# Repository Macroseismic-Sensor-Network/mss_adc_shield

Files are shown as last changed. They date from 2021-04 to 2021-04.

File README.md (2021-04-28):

# MSS ADC Shield

This repository contains the [KiCad](https://www.kicad.org/) design files of the MSS ADC Shield for the [Raspberry Pi](https://www.raspberrypi.org). A PDF of the schematic can be found in the *pdf* folder and the PCB layout files are available in Gerber format in the *gerber* folder.

# License
Copyright 2021, Mertl Research GmbH.
Built upon a design by Daniel Frank.
Licensed under the [CERN-OHL-S v2](https://ohwr.org/cern_ohl_s_v2.txt).

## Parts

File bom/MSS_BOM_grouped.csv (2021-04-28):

Source: | /home/stefan/01_gtd/04_aktuelleProjekte/2019-13_mss_outreach_netidee/02_meilensteine/20200909_mss_produktion/03_adc_platine/MSS.sch
Date: | Mo 28 Sep 2020 15:02:26 CEST
Tool: | Eeschema 5.1.6-c6e7f7d~87~ubuntu18.04.1
Number of components: | 49
ref | value | quantity | manufacturer | manufacturer part number | package | description | footprint | library | part name
C1,C10,C11,C20,C21,C30,C31 | 1uF | 7 | Samsung Electro-Mechanics | CL21B105KBFNNNF | 0805 | Samsung, CL, SMD MLCC, Vielschicht Keramikkondensator X7R, 1μF ±10% / 50V dc, Gehäuse 0805 (2012M) | Capacitor_SMD:C_0805_2012Metric | symbols | C_Small
CON1 | IPL1-104-01-L-S-RE1 | 1 | Samtec | IPL1-104-01-L-S-RE1 | IPL1-104-01-L-S-RE1 | Samtec IPL1 single row, 4 pins, right angle, raised | footprints:IPL1-104-01-L-S-RE1 | symbols | IPL1-104-01-L-S-RE1
CON2,CON3,CON4 | IPL1-102-01-L-S | 3 | Samtec | IPL1-102-01-L-S-RE1 | IPL1-102-01-L-S-RE1 | Samtec IPL1 single row, 2 pins, straight | footprints:IPL1-102-01-L-S | symbols | IPL1-102-01-L-S
D2 | BZT52C2V0S-7-F | 1 | Diodes Incorporated | BZT52C2V0S-7-F | SOD-323 | Zener Diode, 2.0V, 200mW, 5% | Diode_SMD:D_SOD-323 | Device | D_Zener_Small_ALT
D3 | 150080VS75000 | 1 | Würth Elektronik | 150080VS75000 | 0805 | WL-SMCW SMT Mono-color Chip LED Waterclear, green | LED_SMD:LED_0805_2012Metric | Device | LED
D4,D5,D6,D7 | 150080RV54050 | 4 | Würth Elektronik | 150080RV54050 | WL-SBCD-0805 | WL-SBCD SMT Bi-color Chip LED Diffused, red - green | footprints:WL-SBCD-0805 | symbols | 150080RV54050
J1 | RPi | 1 | Samtec | ESQ-120-44-L-D | 20x2 2.54mm pitch | Elevated Socket Strip, 2.54mm Pitch | footprints:RPi_Socket_Strip_Straight_2x20_Pitch2.54mm | Connector_Generic | Conn_02x20_Odd_Even
Q1 | FDS6576 | 1 | ON Semiconductor | FDS6576 | SO-8 | P-Channel MOSFET, 20V DS, 11A, +/-12V GS, 14 mOhm | footprints:ON_751EB_SOIC-8 | symbols | FDS6576
R1,R10,R20,R30 | 1k8 | 4 | TE Connectivity | CRG0805F1K8 | 0805 | TE Connectivity CRG SMD Dickschichtwiderstand, 1,8kΩ ±1% 0,125W, 0805 | Resistor_SMD:R_0805_2012Metric | symbols | R_Small
R2,R4,R5,R6,R7,R8,R9,R15 | 680 | 8 | TE Connectivity | CRG0805F680R | 0805 | TE Connectivity CRG SMD Dickschichtwiderstand, 680Ω ±1% 0,125W, 0805 | Resistor_SMD:R_0805_2012Metric | symbols | R_Small
R11,R12,R21,R22,R31,R32 | 100k | 6 | TE Connectivity | CRG0805F100K | 0805 | TE Connectivity CRG SMD Dickschichtwiderstand, 100kΩ ±1% 0,125W, 0805 | Resistor_SMD:R_0805_2012Metric | symbols | R_Small
R13,R14,R23,R24,R33,R34 | 6k2 | 6 | TE Connectivity | CRCW08056K20FKEA | 0805 | TE Connectivity CRG SMD Dickschichtwiderstand, 6,2kΩ ±1% 0,125W, 0805 | Resistor_SMD:R_0805_2012Metric | symbols | R_Small
R16 | 1k5 | 1 | TE Connectivity | CRG0805F1K5 | 0805 | TE Connectivity CRG SMD Dickschichtwiderstand, 1,5kΩ ±1% 0,125W, 0805 | Resistor_SMD:R_0805_2012Metric | symbols | R_Small
SW1 | 430152043836 | 1 | Würth Elektronik | 430152043836 | 6mm x 6mm | WS-TASV SMT Tact Switch 6x6 mm | footprints:Push_Button_6x6 | Switch | SW_Push
U1,U2,U3 | ADS1114 | 3 | Texas Instruments | ADS1114IDGST | TSSOP10 | ADS111x Ultra-Small, Low-Power, I 2 C-Compatible, 860-SPS, 16-Bit ADCsWith Internal Reference, Oscillator, and Programmable Comparator | Package_SO:TSSOP-10_3x3mm_P0.5mm | symbols | ADS1114
VR1 | 1812L110/33MR | 1 | Littlefuse | 1812L110/33MR | PF1812L | Littelfuse 1.1A Surface Mount Resettable Fuse, 33 V dc | footprints:PF1812L | symbols | Varistance

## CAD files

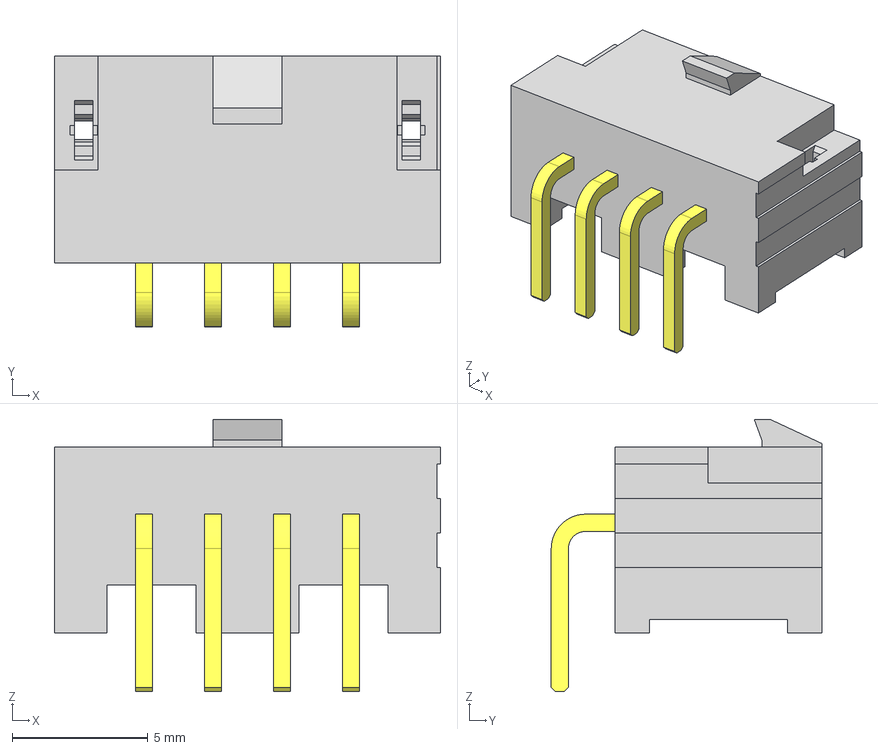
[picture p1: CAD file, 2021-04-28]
3d_models/samtec/IPL1-104-01-L-S-RE1-K.stp
14.2 x 9.97 x 10.0 mm
_IPL1-104-01-S-RE1-K_HDR
_T-1S64-01-04-S-RE1

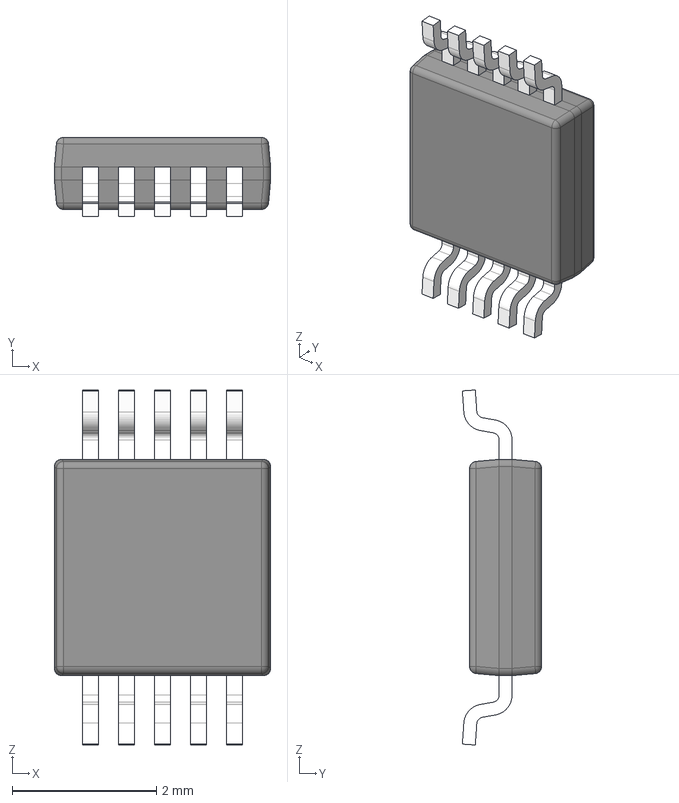
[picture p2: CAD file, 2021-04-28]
3d_models/texas_instruments/ADS1114_DGS0010A.stp
3.00 x 1.10 x 4.93 mm
BODY-SO
LEAD-SO x 10
PIN1-ID

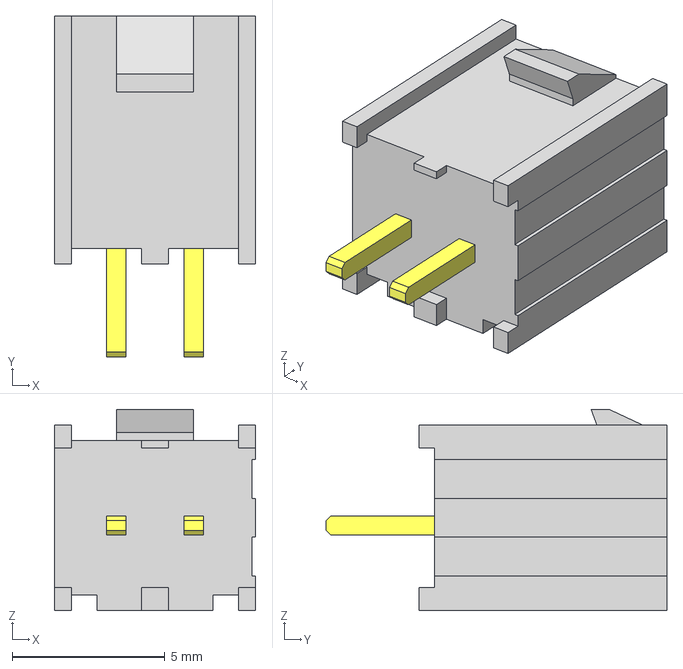
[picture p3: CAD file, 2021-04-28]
3d_models/samtec/IPL1-102-01-L-S-K.stp
6.60 x 11.2 x 6.60 mm
_IPL1-102-01-S-K_HDR
_T-1S64-01-02-S

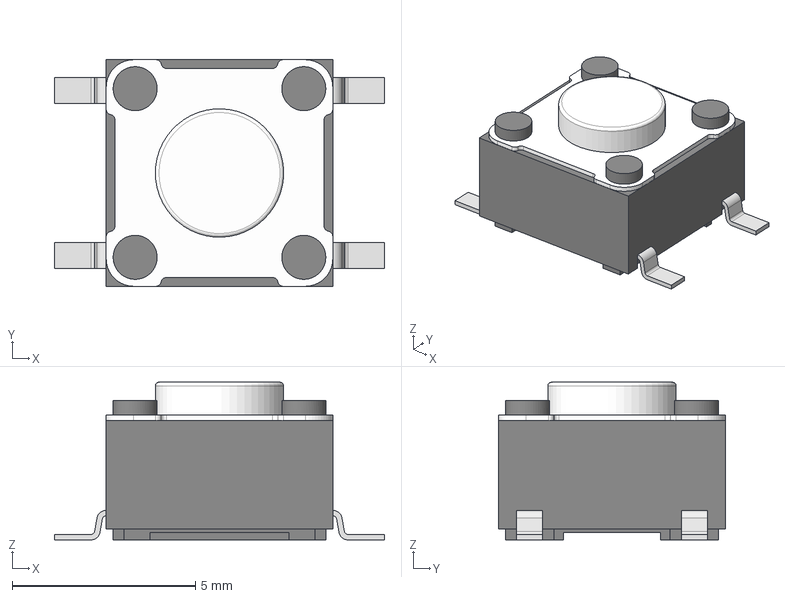
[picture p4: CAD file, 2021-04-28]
3d_models/wuerth_elektronik/430152043836_Download_STP_430152043836_rev1.stp
9.00 x 6.20 x 4.30 mm

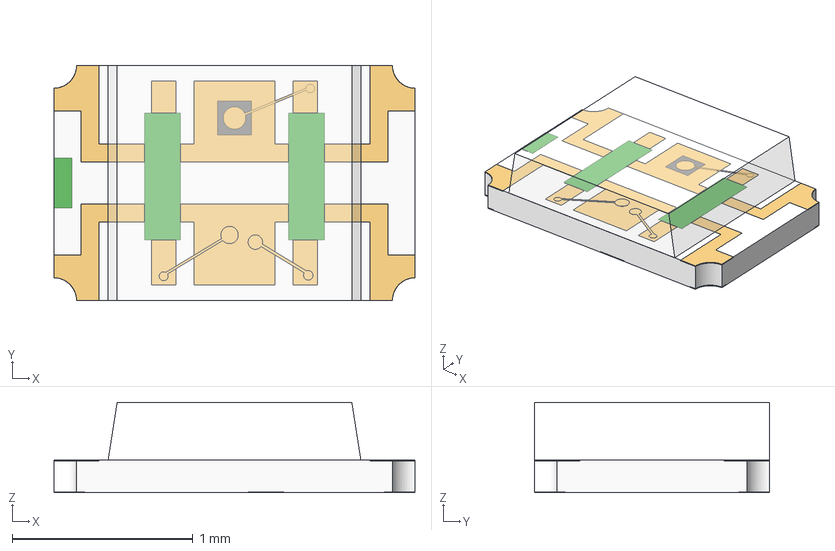
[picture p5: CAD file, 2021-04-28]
3d_models/wuerth_elektronik/150080RV54050_Download_STEP_150080xx54050_rev1.stp
2.00 x 1.30 x 0.501 mm
Pins
Dome

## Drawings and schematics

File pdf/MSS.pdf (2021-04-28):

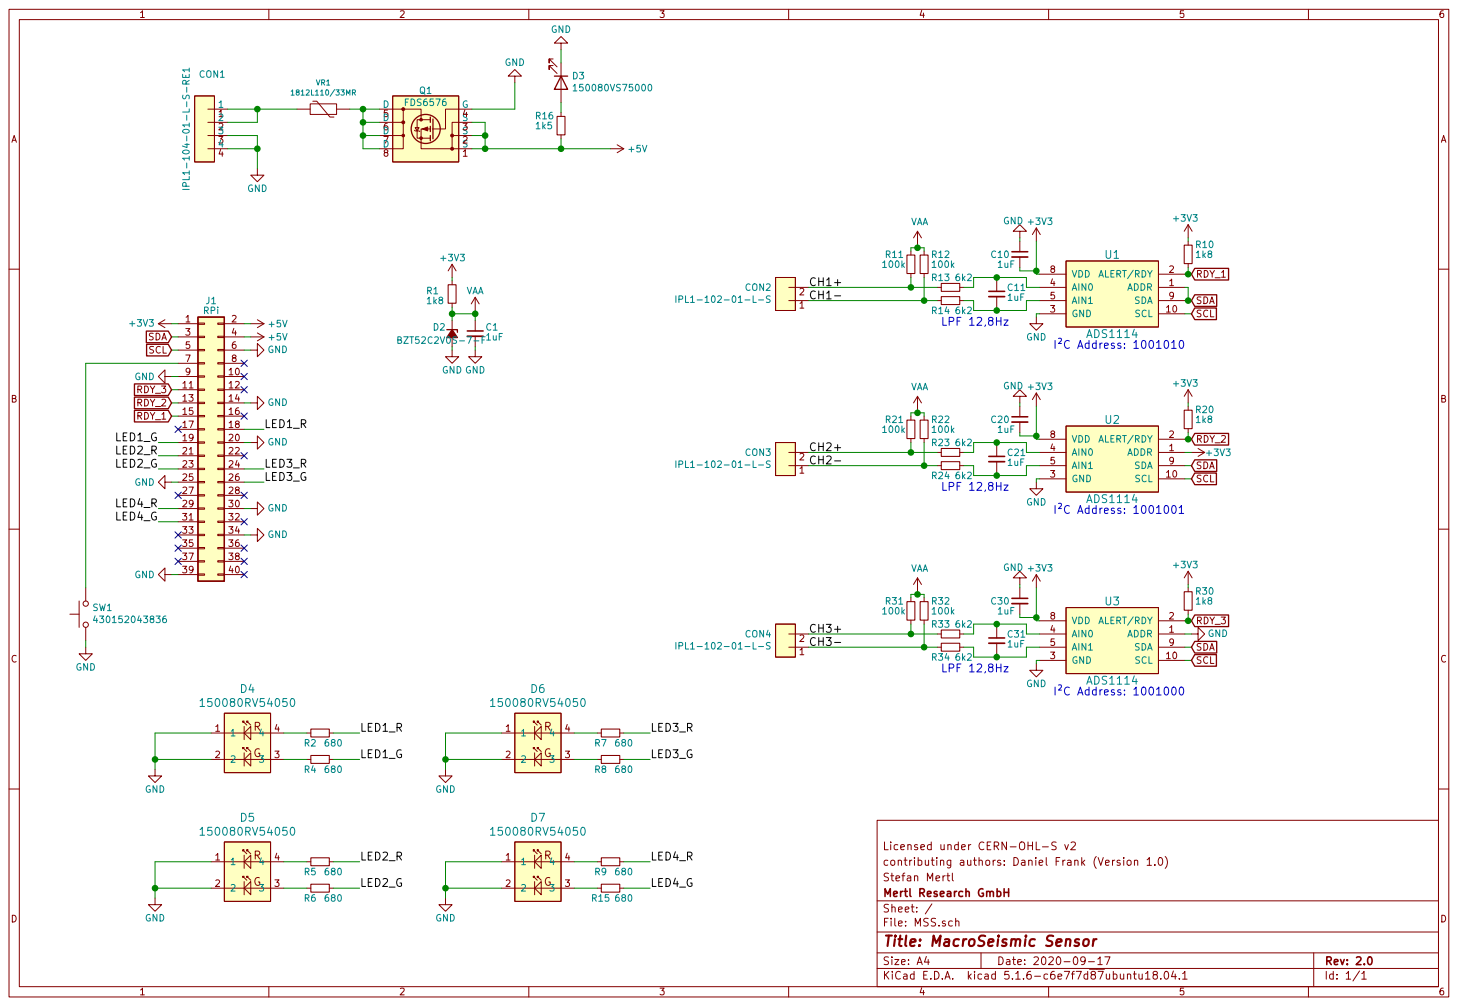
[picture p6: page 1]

RDY_1 SDA RDY_2 SCL SCL RDY_3 SDA

Stefan Mertl contributing authors: Daniel Frank (Version 1.0) Licensed under CERN-OHL-S v2 R15 680

Id: 1/1 Title: MacroSeismic Sensor File: MSS.sch Sheet: / Mertl Research GmbH

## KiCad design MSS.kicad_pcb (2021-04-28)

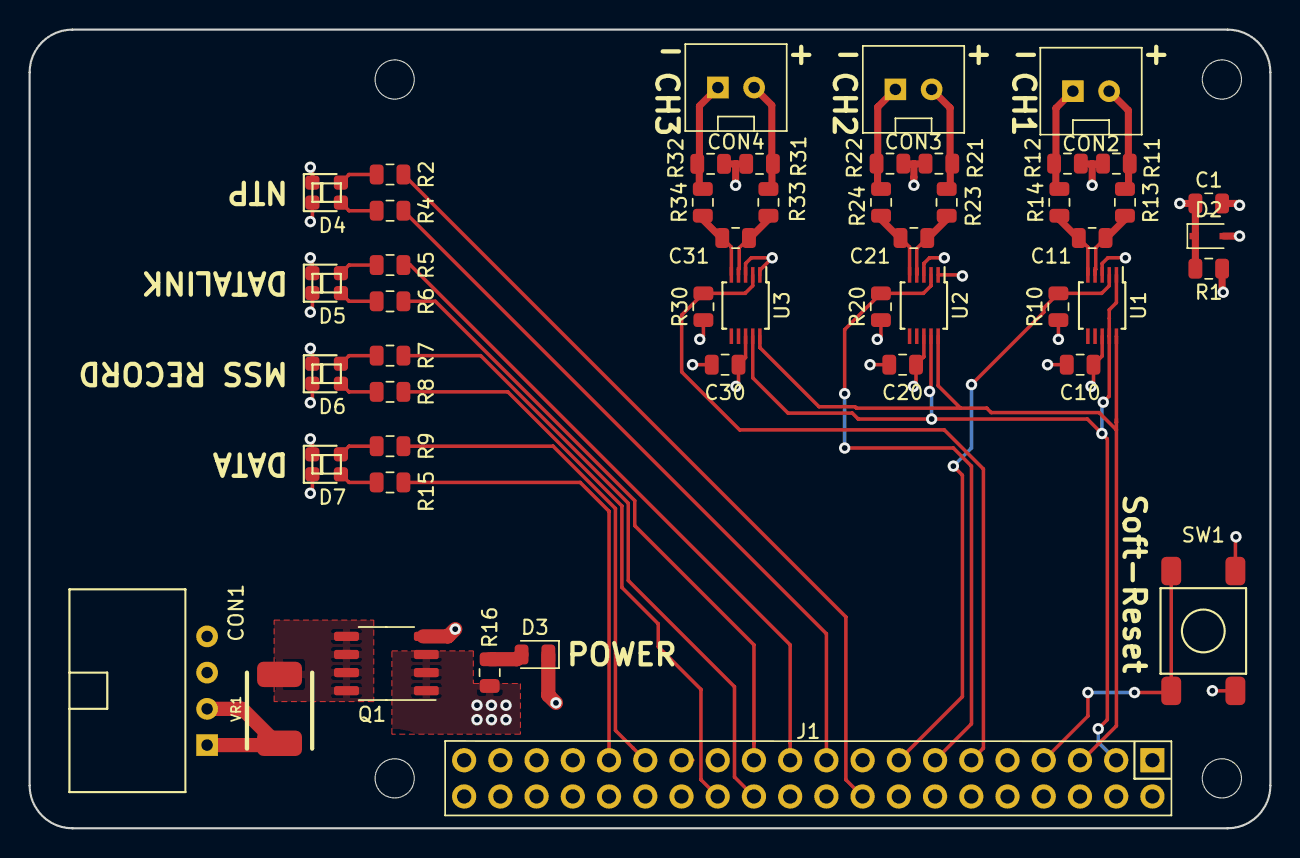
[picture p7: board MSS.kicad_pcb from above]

Board: 4 copper layers, 87.0 x 56.0 mm, 53 parts (0 on the bottom side), 41 nets.

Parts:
C1, C10, C11, C20, C21, C30, C31: 1uF; C_0805_2012Metric
CON1: IPL1-104-01-L-S-RE1
CON2, CON3, CON4: IPL1-102-01-L-S
D2: BZT52C2V0S-7-F; D_SOD-323
D3: 150080VS75000; LED_0805_2012Metric
D4, D5, D6, D7: 150080RV54050; WL-SBCD-0805
J1: RPi; RPi_Socket_Strip_Straight_2x20_Pitch2.54mm
MH1, MH2, MH3, MH4: MountingHole_2.75mm_M2.5
Q1: FDS6576; ON_751EB_SOIC-8
R1, R10, R20, R30: 1k8; R_0805_2012Metric
R2, R4, R5, R6, R7, R8, R9, R15: 680; R_0805_2012Metric
R11, R12, R21, R22, R31, R32: 100k; R_0805_2012Metric
R13, R14, R23, R24, R33, R34: 6k2; R_0805_2012Metric
R16: 1k5; R_0805_2012Metric
SW1: 430152043836; Push_Button_6x6
U1, U2, U3: ADS1114; TSSOP-10_3x3mm_P0.5mm
VR1: 1812L110/33MR; PF1812L

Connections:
+3V3: C10.2, C20.2, C30.2, J1.1, R1.1, R10.1, R20.1, R30.1, U1.8, U2.1, U2.8, U3.8
+5V: J1.2, J1.4, Q1.1, Q1.2, Q1.3, R16.2
/CH1+: CON2.2, R11.2, R13.2
/CH1-: CON2.1, R12.2, R14.2
/CH2+: CON3.2, R21.2, R23.2
/CH2-: CON3.1, R22.2, R24.2
/CH3+: CON4.2, R31.2, R33.2
/CH3-: CON4.1, R32.2, R34.2
/LED1_G: J1.19, R4.1
/LED1_R: J1.18, R2.1
/LED2_G: J1.23, R6.1
/LED2_R: J1.21, R5.1
/LED3_G: J1.26, R8.1
/LED3_R: J1.24, R7.1
/LED4_G: J1.31, R15.1
/LED4_R: J1.29, R9.1
GND: C1.2, C10.1, C20.1, C30.1, CON1.3, CON1.4, D2.2, D3.1, D4.1, D4.2, D5.1, D5.2, D6.1, D6.2, D7.1, D7.2, J1.6, J1.9, J1.14, J1.20, J1.25, J1.30, J1.34, J1.39, Q1.4, SW1.1, U1.3, U2.3, U3.1, U3.3
unnamed: C11.1, R13.1, U1.4
unnamed: C11.2, R14.1, U1.5
unnamed: C21.1, R23.1, U2.4
unnamed: C21.2, R24.1, U2.5
unnamed: C31.1, R33.1, U3.4
unnamed: C31.2, R34.1, U3.5
unnamed: CON1.1, CON1.2, VR1.1
unnamed: D3.2, R16.1
unnamed: D4.3, R4.2
unnamed: D4.4, R2.2
unnamed: D5.3, R6.2
unnamed: D5.4, R5.2
unnamed: D6.3, R8.2
unnamed: D6.4, R7.2
unnamed: D7.3, R15.2
unnamed: D7.4, R9.2
unnamed: J1.7, SW1.2
unnamed: Q1.5, Q1.6, Q1.7, Q1.8, VR1.2
RDY_1: J1.15, R10.2, U1.2
RDY_2: J1.13, R20.2, U2.2
RDY_3: J1.11, R30.2, U3.2
SCL: J1.5, U1.10, U2.10, U3.10
SDA: J1.3, U1.1, U1.9, U2.9, U3.9
VAA: C1.1, D2.1, R1.2, R11.1, R12.1, R21.1, R22.1, R31.1, R32.1

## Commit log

2021-04-28 Initial commit.
    [150080RV54050_Download_STEP_150080xx54050_rev1.stp, 430152043836_Download_STP_430152043836_rev1.stp, ADS1114_DGS0010A.stp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]
2021-04-28 Added temporary Kicad files.
2021-04-28 Added the CERN-OHL-S v2 license.
    [MSS.kicad_pcb, MSS.sch]
2021-04-28 Added the schematic pdf and gerber files of the PCB.
    [MSS-B_Cu.gbl, MSS-B_Mask.gbs, MSS-B_SilkS.gbo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]

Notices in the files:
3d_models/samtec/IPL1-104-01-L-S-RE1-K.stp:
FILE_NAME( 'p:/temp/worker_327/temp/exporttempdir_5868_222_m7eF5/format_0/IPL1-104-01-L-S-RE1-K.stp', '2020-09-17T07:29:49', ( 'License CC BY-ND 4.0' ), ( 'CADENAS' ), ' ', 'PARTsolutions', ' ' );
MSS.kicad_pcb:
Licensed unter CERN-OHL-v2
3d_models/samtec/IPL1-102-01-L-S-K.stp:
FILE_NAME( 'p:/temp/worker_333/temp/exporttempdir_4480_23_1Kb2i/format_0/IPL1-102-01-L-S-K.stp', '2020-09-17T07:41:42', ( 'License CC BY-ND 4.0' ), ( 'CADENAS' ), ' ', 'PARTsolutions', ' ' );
